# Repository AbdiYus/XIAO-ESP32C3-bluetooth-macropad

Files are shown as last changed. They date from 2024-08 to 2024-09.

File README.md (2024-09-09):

# XIAO-ESP32C3 bluetooth Macropad (C3_Pad) 
A custom Macropad using a Xiao esp32c3 micorcontroller. 

This projects includes: 
- Arduino sketch
- PCB design
- Bill of material 
- 3d print case 

## Arduino sketch 
The project requires these libraries to compile: 
- [Encoder by Paul Stoffregen](https://github.com/PaulStoffregen/Encoder)
- [u8g2 by olikarus](https://github.com/olikraus/u8g2)
- [ESP32-BLE-Combo by Georgegipa](https://github.com/Georgegipa/ESP32-BLE-Combo)

## PCB design
I'm new to PCB design and __highly recommend__ you to check it out before using the design. 

### Schematic 
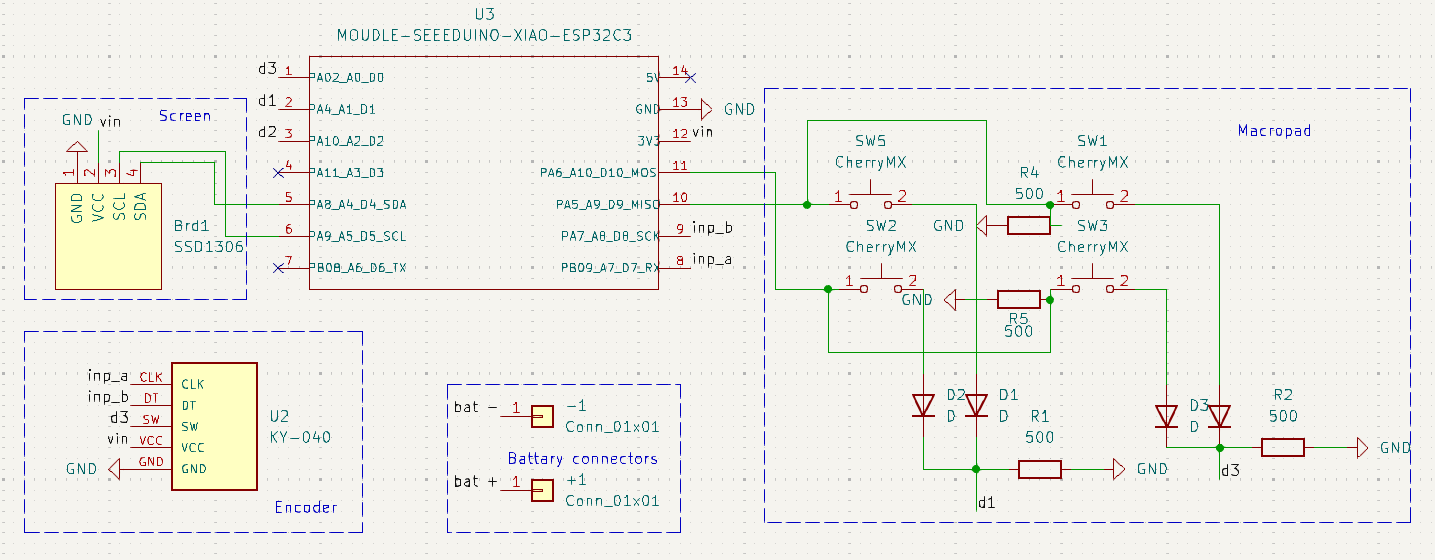
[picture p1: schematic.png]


__N.B!__ 
The xiao esp32c3 symbol doesn't include the battery connectors. So, I've manualy connected them on the PCB editor

### pcb
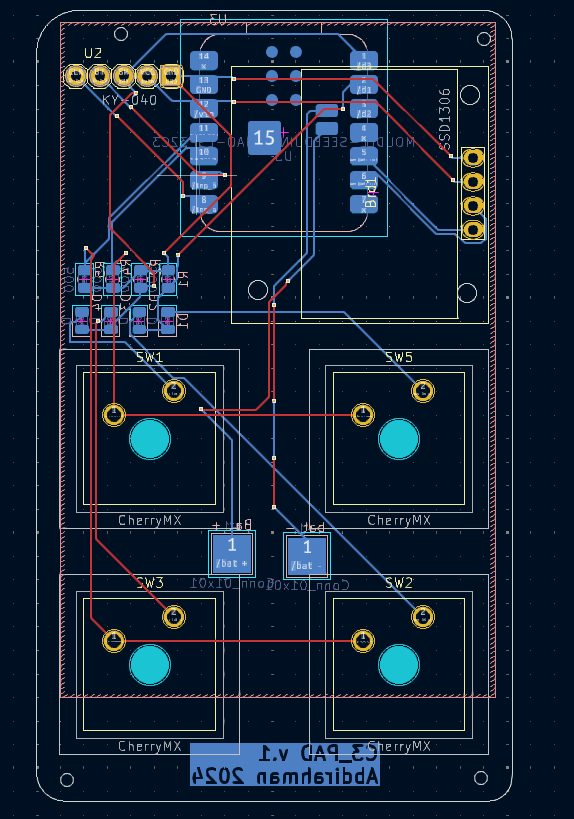
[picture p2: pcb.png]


### 3d model
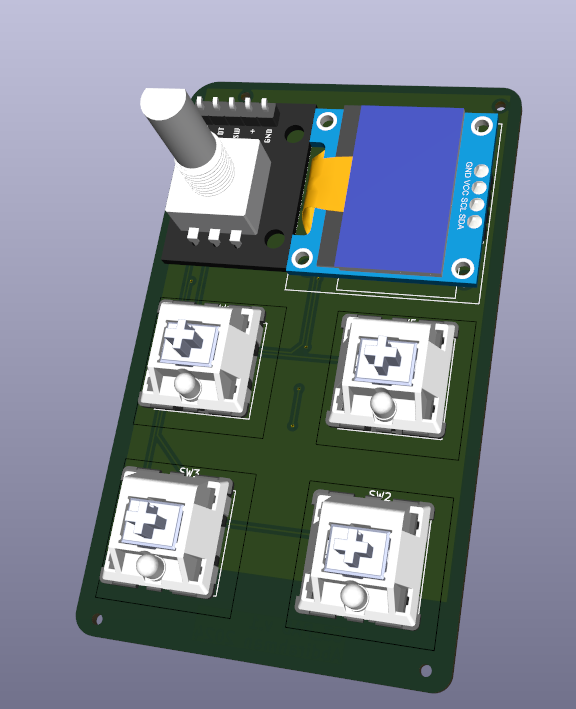
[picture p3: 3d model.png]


# Bill of material (BOM)
| component | website | 
| --- | --- |
| SSD1306 OLED | [link](https://www.amazon.com/HiLetgo-Adafruit-Beaglebones-Raspberry-Optional/dp/B06XRBYJR8?th=1) |
| KY-040 encoder | [link](https://www.amazon.com/JTAREA-KY-040-Encoder-Encoders-Modules/dp/B0D2TW63G1/ref=sr_1_1_sspa?) |
| TP4056 charger | [link](https://www.amazon.com/HiLetgo-Lithium-Charging-Protection-Functions/dp/B07PKND8KG/ref=sr_1_1_sspa?) |
| Cherry MX silent red  | [link](https://www.amazon.com/Cherry-MX-RGB-Mechanical-Keyboard/dp/B0CBS4QYXS/ref=sr_1_1?) |
| Xiao ESP32c3 | [link](https://www.seeedstudio.com/Seeed-XIAO-ESP32C3-p-5431.html) |

# 3d print case 
__Not finished__

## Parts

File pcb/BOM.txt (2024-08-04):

tp4056 LIPO batteri regulator	https://elkim.no/produkt/1a-usb-lithium-tp4056-batterilader-battery-charging-module-with-protection/	1stk	38kr
Switch	cherry MX silent	https://www.maxgaming.no/no/switchar/mx2a-red	10stk	53,9kr 
PCB	PCBWAY	5stk	332kr (oof...)

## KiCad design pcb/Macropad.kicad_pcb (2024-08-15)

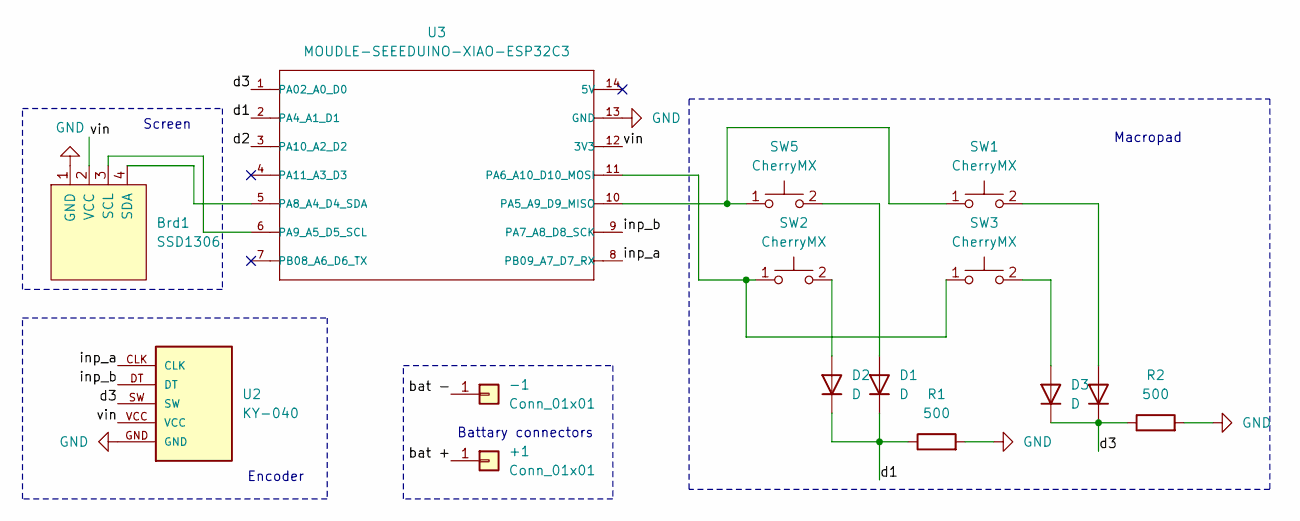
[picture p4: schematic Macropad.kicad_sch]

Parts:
+1: Conn_01x01; TestPoint_Pad_4.0x4.0mm
-1: Conn_01x01; TestPoint_Pad_4.0x4.0mm
Brd1: SSD1306; 128x64OLED
D1, D2, D3, D4: D; D_0805_2012Metric
R1, R2: 500; R_0805_2012Metric
SW1, SW2, SW3, SW5: CherryMX; CherryMX_1.00u
U2: KY-040; KY-040-PORT
U3: MOUDLE-SEEEDUINO-XIAO-ESP32C3; MCU_Seeed_ESP32C3

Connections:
/bat +: +1.1, U3.16
/bat -: -1.1, U3.17
/d1: D1.1 (K), D2.1 (K), R1.1, U3.2 (PA4_A1_D1)
/d2: U3.3 (PA10_A2_D2)
/d3: D3.1 (K), D4.1 (K), R2.1, U2.SW, U3.1 (PA02_A0_D0)
/inp_a: U2.CLK, U3.8 (PB09_A7_D7_RX)
/inp_b: U2.DT, U3.9 (PA7_A8_D8_SCK)
/vin: Brd1.2 (VCC), U2.VCC, U3.12 (3V3)
GND: Brd1.1 (GND), R1.2, R2.2, U2.GND, U3.13 (GND)
unnamed: Brd1.3 (SCL), U3.6 (PA9_A5_D5_SCL)
unnamed: Brd1.4 (SDA), U3.5 (PA8_A4_D4_SDA)
unnamed: D1.2 (A), SW5.2
unnamed: D2.2 (A), SW2.2
unnamed: D3.2 (A), SW3.2
unnamed: D4.2 (A), SW1.2
unnamed: SW1.1, SW5.1, U3.10 (PA5_A9_D9_MISO)
unnamed: SW2.1, SW3.1, U3.11 (PA6_A10_D10_MOSI)

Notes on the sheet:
Encoder
Battary connectors
Macropad
Screen

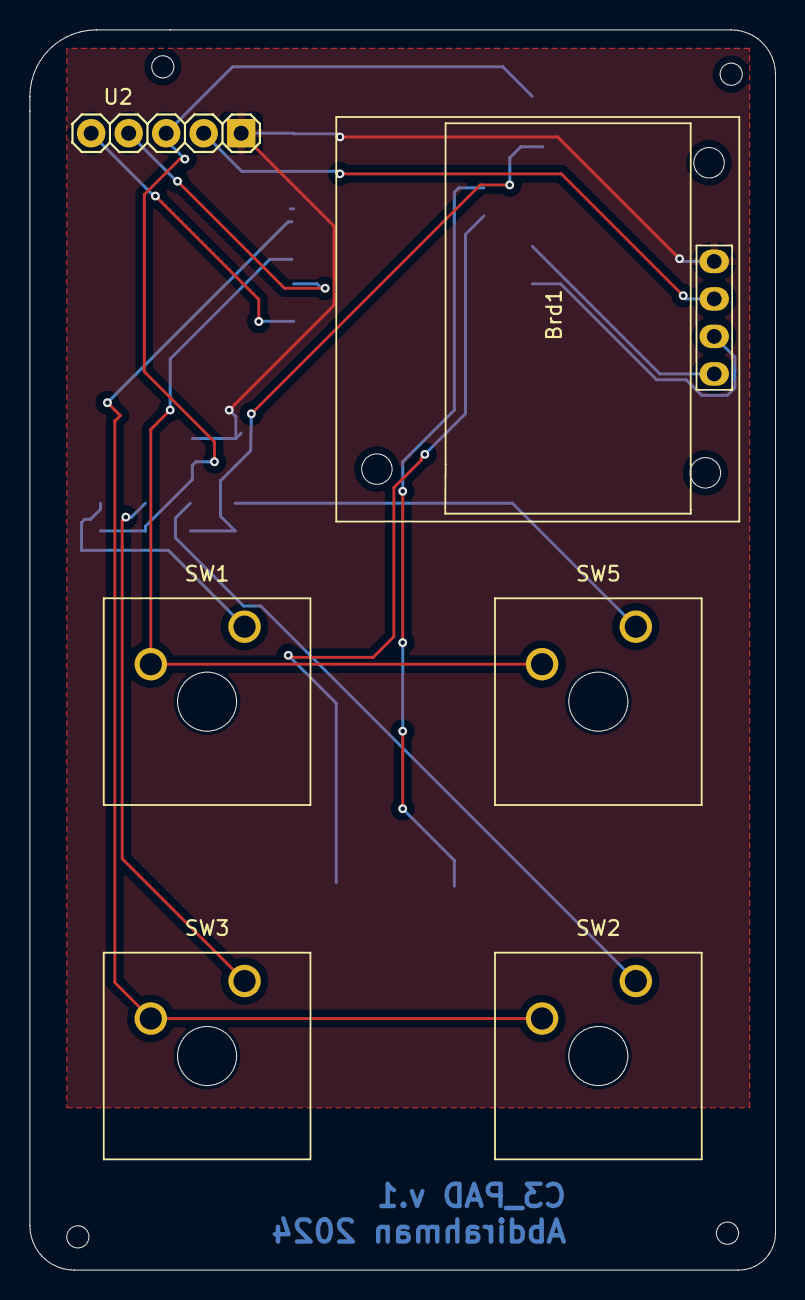
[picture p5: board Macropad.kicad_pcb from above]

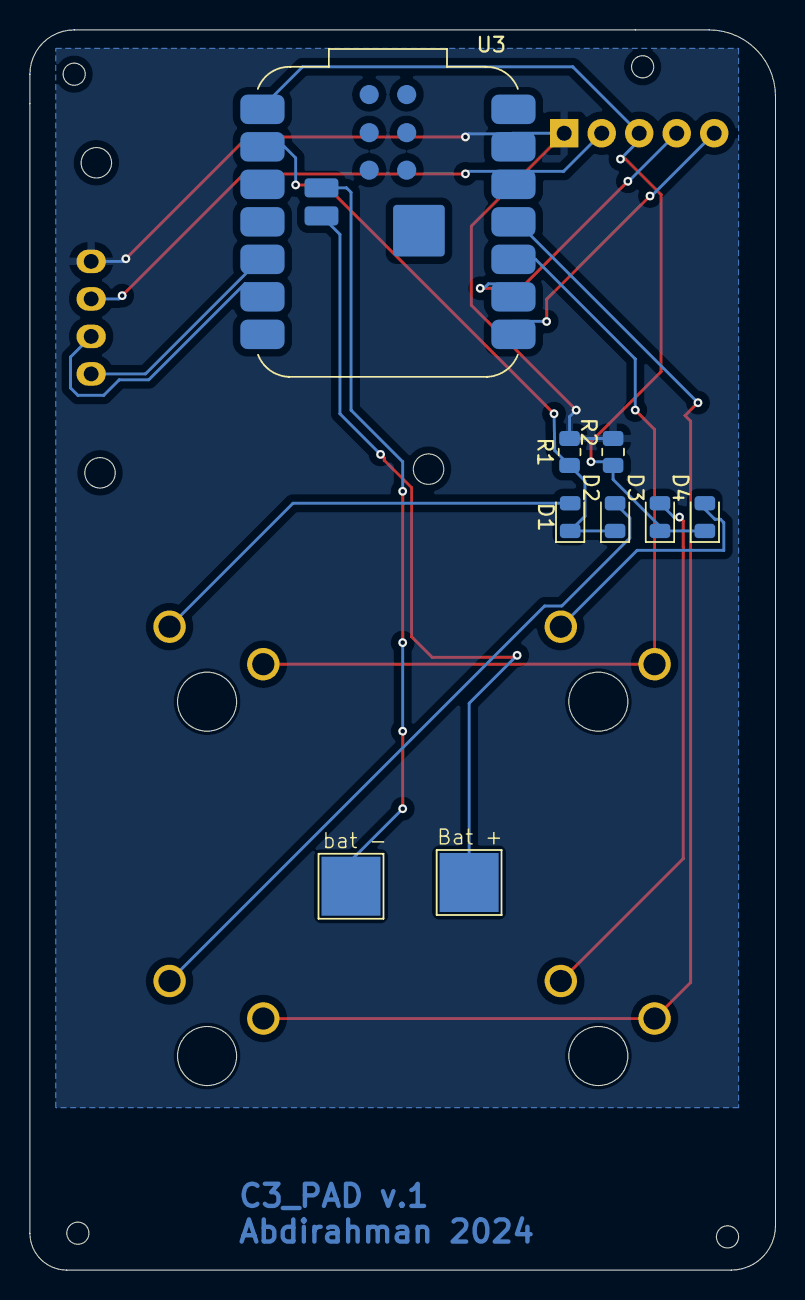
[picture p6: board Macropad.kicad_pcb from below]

Board: 2 copper layers, 50.5 x 84.0 mm, 15 parts (9 on the bottom side), 16 nets.

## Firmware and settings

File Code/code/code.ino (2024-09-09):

/**
*   This is the main file for the project. It contains the setup and 
*   loop functions for the xiao esp32c3 macropad.
*
*   @file code.ino
*   @author Abdirahman Ahmed Yusuf
*/
#include "functions.h"
#include <esp_sleep.h>

RTC_DATA_ATTR unsigned long lastActiveTime; 

void setup() {
  functions::initKeyPad();
  Serial.begin(115200);

  esp_sleep_wakeup_cause_t wakeupReason = esp_sleep_get_wakeup_cause(); 
  if(wakeupReason == ESP_SLEEP_WAKEUP_EXT1) Serial.println("Woke up!");
  else  Serial.println("Reset or woke up for some other reason...");

  esp_deep_sleep_enable_gpio_wakeup(BIT(D3), ESP_GPIO_WAKEUP_GPIO_LOW);
  lastActiveTime = millis();
}

void loop() {
  if(digitalRead(col_2) == LOW)   functions::checkKeyPad(col_1);
  if(digitalRead(col_1) == LOW)   functions::checkKeyPad(col_2);
  functions::scroll();

  if(isAnythingPressed) {
    lastActiveTime = millis();  isAnythingPressed = false;
  } 
  if(millis() - lastActiveTime > sleep_timeout) {
    screen::clear();
    esp_deep_sleep_start(); 
  }
}

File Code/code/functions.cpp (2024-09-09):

#include "functions.h"

Encoder en(input_a, input_b); /*   Rotary encoder    */
volatile long position = -999;
volatile int direction = 1;
bool wasCon = false;
bool isAnythingPressed = false; 
int timeNow = 50; 


/**
*   initKeypad() sets the pins for the keypad matrix, and
*   the library Keyboard.
*/
void functions::initKeyPad() {
  pinMode(row_1, INPUT);
  pinMode(row_2, INPUT);
  pinMode(col_1, OUTPUT);
  pinMode(col_2, OUTPUT);

  /*  Libraries  */
  Keyboard.begin();
  screen::init();

  // set everything to low
  digitalWrite(col_1, LOW);
  digitalWrite(col_2, LOW);

  screen::show(keyStroke::connected);
}

/**
*   checkKeyPad() checks the keypad matrix for a key press.
*
*   @param int col - the column to check
*/
void functions::checkKeyPad(int col) { /* TODO ADD BOOL AND SLEEP FUNCTION!!!!!*/
  /*  connection update  */
  if(!keyStroke::connected() || (keyStroke::connected() && wasCon)) {
    wasCon = keyStroke::connected() ? false : true;
    screen::show(keyStroke::connected());
    return;
  }

  digitalWrite(col, HIGH);
  functions::findKey();
  if(millis() - timeNow >= 100) {
    timeNow = millis(); 
    digitalWrite(col, LOW);
  }
}

/**
*   findKey() finds the key pressed on the keypad matrix. (position)
*/
void functions::findKey() {
  int inputRow_1 = 0; // row reading (first row)
  int lastRowState_1 = 0; // last row reading (first row)
  int inputRow_2 = 0; // row reading (secound row)
  int lastRowState_2 = 0; // last row state (secound row)

  inputRow_1 = digitalRead(row_1);
  inputRow_2 = digitalRead(row_2);

  if((inputRow_1) && (inputRow_2)) {
    screen::changeMode();
    while((inputRow_1) && (inputRow_2)) {
      inputRow_1 = digitalRead(row_1);
      inputRow_2 = digitalRead(row_2);
    }
    return;
  }

  if(inputRow_1) {
    if(digitalRead(col_1) == HIGH) {
      screen::show(true, 4);  isAnythingPressed = true;
      mode == 1 ? keyStroke::paste() : keyStroke::explorer();
    }
    if(digitalRead(col_2) == HIGH) {
      screen::show(true, 3);  isAnythingPressed = true;
      mode == 1 ? keyStroke::copy() : keyStroke::terminal();
    }

    lastRowState_1 = inputRow_1;
    while(inputRow_1 == lastRowState_1) inputRow_1 = digitalRead(row_1);
    screen::show(true);
  }

  if(inputRow_2) {
    if(digitalRead(col_1) == HIGH) {
      screen::show(true, 2);  isAnythingPressed = true;
      mode == 1 ? keyStroke::screenShot() : keyStroke::undo();
    }
    if(digitalRead(col_2) == HIGH) {
      screen::show(true, 1);  isAnythingPressed = true;
      mode == 1 ? keyStroke::altTab() : keyStroke::comment();
    }

    lastRowState_2 = inputRow_2;
    while(inputRow_2 == lastRowState_2) inputRow_2 = digitalRead(row_2);
    screen::show(true);
  }
}

signed char functions::mapEncoder(long val, long min, long max) {
  long output = map(val, min, max, -128, 127);
  output = constrain(output, -1, 1);
  return static_cast<signed char>(output);
}

void functions::scroll() {
  if(!keyStroke::connected()) return;
  long val;   int result, currentDir;
  /*   Error handling if the value is a ASCII   */
  if(Serial.available())  en.write(0);

  /*   Sending direction value of the encoder   */
  val = en.read();
  if(val != position) {
    currentDir = (val - position) > 0 ? 1 : -1;
    if(currentDir != direction) {
      isAnythingPressed = true;
      if(currentDir == 1) en.write(11); // offset number for encoder
      else en.write(-3);
    }
    Mouse.move(0, 0, mapEncoder(position, -999, 999));
    position = val;
    direction = currentDir;
  }
}

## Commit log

2024-01-07 inital pcb
    [pcb.kicad_sch]
2024-01-09 added keyboard libraries
    [pcb.kicad_sch]
2024-08-04 added encoder + setup to screen
    [pcb.kicad_pcb, pcb.kicad_sch]
2024-08-04 pcb v.01
    [Macropad.kicad_pcb, Macropad.kicad_sch, pcb.kicad_pcb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]
